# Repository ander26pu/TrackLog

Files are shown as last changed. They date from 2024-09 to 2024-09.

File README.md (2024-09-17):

# TrackLog
- Placa de pruebas: [LILYGO-T18](https://github.com/LilyGO/LILYGO-T-Energy)
- GPS Neo 8MN
- Pantalla OLED 0.96''
- Acelerómetro y giroscopio BMI160
- RTC DS3231
- Módulo micro SD card

## Pines Utilizados

En esta sección se detallan los pines utilizados en el proyecto para los diferentes periféricos conectados al microcontrolador.

| Componente | Pin de Microcontrolador | Función |
|---|---|---|
| **Pantalla OLED (SSD1306)** | I2C SDA (GPIO 21) | Comunicación I2C (SDA) |
| | I2C SCL (GPIO 22) | Comunicación I2C (SCL) |
| **GPS (UART)** | RX1 (GPIO 19) | Recepción de datos (RX) |
| | TX1 (GPIO 18) | Transmisión de datos (TX) |
| **Tarjeta SD** | CS (GPIO 15) | Chip Select (CS) |
| | MOSI (GPIO 13) | Master Out Slave In (MOSI) |
| | MISO (GPIO 12) | Master In Slave Out (MISO) |
| | SCK (GPIO 14) | Serial Clock (SCK) |
| **Acelerómetro/Giroscopio (BMI160)** | I2C SDA (GPIO 21) | Comunicación I2C (SDA) |
| | I2C SCL (GPIO 22) | Comunicación I2C (SCL) |
| **RTC (DS3231)** | I2C SDA (GPIO 21) | Comunicación I2C (SDA) |
| | I2C SCL (GPIO 22) | Comunicación I2C (SCL) |

### Notas adicionales:

- **I2C:** Varios componentes (OLED, acelerómetro/giroscopio, RTC) comparten el bus I2C. Asegúrate de que cada dispositivo tenga una dirección I2C única.
- **SPI:** La tarjeta SD se comunica a través del bus SPI. El pin CS (Chip Select) se define en el código, y el resto de los pines de SPI son comunes a todos los dispositivos SPI.
- **GPS (UART):** El GPS utiliza UART para la comunicación. En este caso, se ha configurado para utilizar UART1.

## PCB TrackLog Shield

Este proyecto incluye el diseño de un **PCB Shield** que se conecta directamente encima de la placa de pruebas [LILYGO-T18](https://github.com/LilyGO/LILYGO-T-Energy). El Shield está diseñado para expandir las capacidades de la placa base, facilitando la conexión de sensores y otros componentes necesarios para el desarrollo del sistema embebido.

### Características del PCB

- **Compatibilidad**: Diseñado específicamente para la placa [LILYGO-T18](https://github.com/LilyGO/LILYGO-T-Energy).
- **Conexiones adicionales**: El Shield incluye pines accesibles para facilitar la conexión de módulos y sensores adicionales.
- **Tamaño compacto**: Encaja directamente sobre la placa LILYGO-T18 sin necesidad de adaptadores adicionales.
- **Facilidad de ensamblaje**: Diseño optimizado para una rápida producción y ensamblaje.

### Esquema del PCB

A continuación se presenta el esquema del diseño del PCB. Este esquema detalla las conexiones entre la placa LILYGO-T18 y los componentes adicionales del Shield.

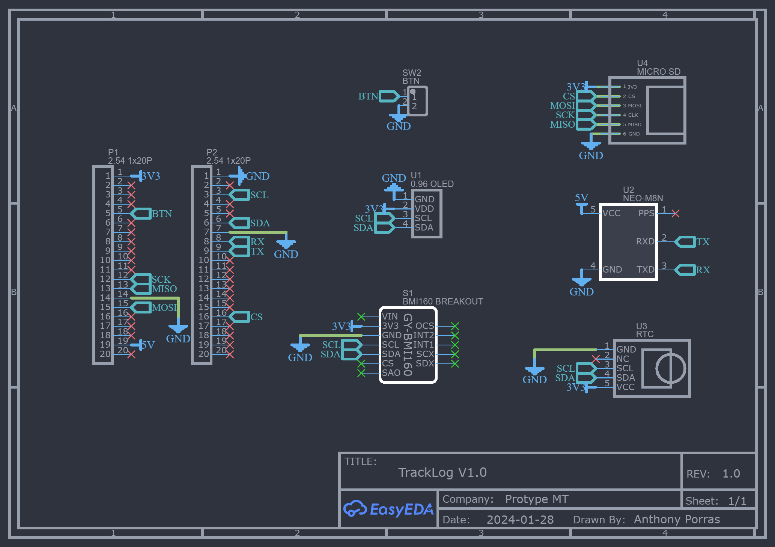
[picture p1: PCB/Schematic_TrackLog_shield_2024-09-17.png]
Esquema del PCB


### Layout del PCB

En el diseño de la PCB se utilizó un ancho de pista de 0.5mm y un espaciado de 0.25mm.

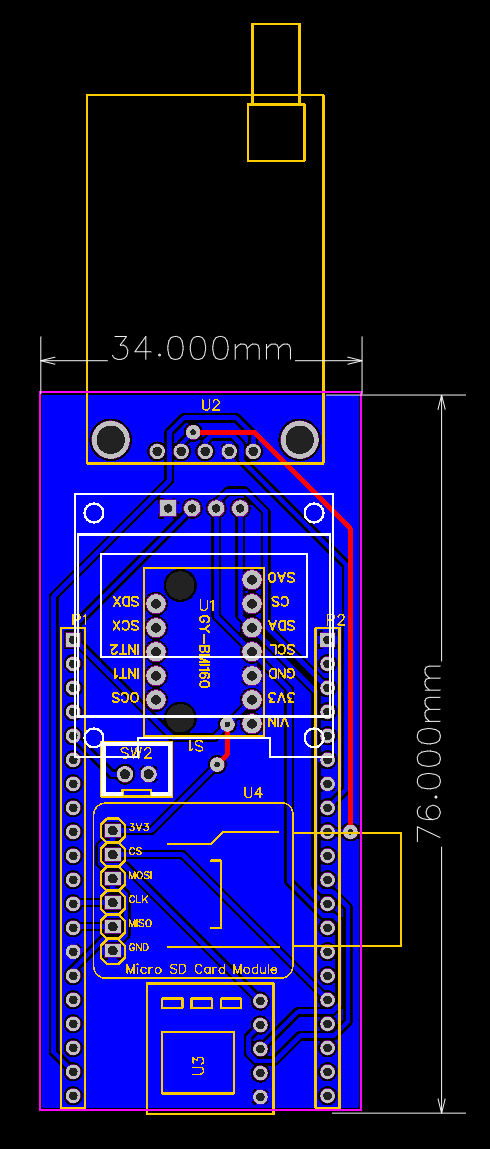
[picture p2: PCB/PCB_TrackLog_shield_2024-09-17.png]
Layout del PCB


### Archivos Gerber y BOM

Puedes descargar los archivos Gerber para la fabricación del Shield desde el siguiente enlace:

- [Archivos Gerber](PCB/Gerber_PCB_TrackLog_shield_2024-09-17.zip)

### Instrucciones de Montaje

1. **Fabricación**: Utiliza los archivos Gerber para fabricar el PCB.
2. **Componentes**: Sigue la lista de materiales para obtener los componentes necesarios.
3. **Soldadura**: Ensambla los componentes siguiendo el esquema proporcionado.
4. **Montaje en LILYGO-T18**: Coloca el Shield directamente encima de la placa LILYGO-T18, alineando los pines correctamente.

### Vista del PCB ensamblado

Aquí puedes ver cómo luce el PCB Shield una vez ensamblado y conectado a la placa LILYGO-T18:

PCB ensamblado

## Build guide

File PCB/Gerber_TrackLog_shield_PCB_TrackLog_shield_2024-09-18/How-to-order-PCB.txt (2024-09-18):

How to Order PCB

Please refer to:
https://docs.easyeda.com/en/PCB/Order-PCB

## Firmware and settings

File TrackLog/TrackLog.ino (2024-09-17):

// Script: TrackLog V1.0
// Description: Guarda datos del gps con las aceleraciones con fecha y hora en una micro sd, mostrando el estado en una pantalla OLED
// Autor: @ander26pu
// Fecha: 2024-09-16
// Board: LILYGO-T18
// Description: Guarda datos del GPS con las aceleraciones con fecha y hora en una micro SD, mostrando el estado en una pantalla OLED

// Board: LILYGO-T18

#include <Wire.h>
#include <Adafruit_GFX.h>
#include <Adafruit_SSD1306.h>
#include <TinyGPSPlus.h>
#include <HardwareSerial.h>
#include <SPI.h>  // Biblioteca para comunicación SPI
#include <SD.h>   // Biblioteca para manejar la tarjeta SD
#include <DFRobot_BMI160.h>
#include "RTClib.h"

#define I2C_SDA 21
#define I2C_SCL 22

#define SCREEN_WIDTH 128 // Ancho de la pantalla OLED
#define SCREEN_HEIGHT 64 // Alto de la pantalla OLED

// Definir el pin de reinicio, si no se usa, define como -1
#define OLED_RESET    -1

#define HSPI_MISO   12
#define HSPI_MOSI   13
#define HSPI_SCK    14
#define SD_CS_PIN   15  // Cambia este pin según tu diseño

File myFile;

// Inicializar la pantalla con la dirección I2C predeterminada 0x3C
Adafruit_SSD1306 display(SCREEN_WIDTH, SCREEN_HEIGHT, &Wire, OLED_RESET);

// Inicializar la comunicación serial para el GPS
HardwareSerial serialGPS(1); // Usamos UART1 (GPIO 19 y 18 para RX/TX)
TinyGPSPlus gps;             // Instancia del objeto TinyGPSPlus

RTC_DS3231 rtc;

DFRobot_BMI160 bmi160;

const int8_t i2c_addr = 0x69;

void setup() {
  Serial.begin(115200);
  delay(100);
  
  Wire.begin(I2C_SDA, I2C_SCL);
  
  iniciarRTC();
  iniciarBMI160();
  iniciarSD();
  iniciarPantallaOLED();
  iniciarGPS();
}

void loop() {
  leerGPS();
  mostrarDatosEnPantalla();
  guardarDatosSD();
  delay(1000);  // Retardo para que no saturemos la pantalla y la SD
}

// Función para inicializar el RTC
void iniciarRTC() {
  if (!rtc.begin()) {
    Serial.println("No se pudo encontrar el RTC DS3231");
    while (1);
  }
}

// Función para inicializar el sensor BMI160
void iniciarBMI160() {
  if (bmi160.softReset() != BMI160_OK) {
    Serial.println("Error en el reinicio del BMI160");
    while (1);
  }
  
  if (bmi160.I2cInit(i2c_addr) != BMI160_OK) {
    Serial.println("Error en la inicialización del BMI160");
    while (1);
  }
}

// Función para inicializar la tarjeta SD
void iniciarSD() {
  SPI.begin(HSPI_SCK, HSPI_MISO, HSPI_MOSI, SD_CS_PIN);
  
  if (!SD.begin(SD_CS_PIN)) {
    Serial.println("Fallo en la inicialización de la tarjeta SD.");
    while (1);
  } else {
    Serial.println("Tarjeta SD detectada y lista.");
  }
}

// Función para inicializar la pantalla OLED
void iniciarPantallaOLED() {
  if (!display.begin(SSD1306_SWITCHCAPVCC, 0x3C)) {
    Serial.println(F("Fallo al inicializar la pantalla OLED"));
    for (;;);
  }
  display.clearDisplay();
  display.setTextSize(1);
  display.setTextColor(WHITE);
  display.setCursor(0, 10);
  display.println(F("Esperando GPS..."));
  display.display();
}

// Función para inicializar el GPS
void iniciarGPS() {
  serialGPS.begin(9600, SERIAL_8N1, 19, 18);  // Inicializamos el GPS en UART1
}

// Función para leer datos del GPS
void leerGPS() {
  while (serialGPS.available() > 0) {
    gps.encode(serialGPS.read());
  }
}

// Función para mostrar los datos en la pantalla OLED
void mostrarDatosEnPantalla() {
  display.clearDisplay();
  display.setCursor(0, 0);

  if (gps.location.isValid()) {
    display.println(F("GPS Datos:"));
    display.print(F("Lat: "));
    display.println(gps.location.lat(), 6);
    display.print(F("Lon: "));
    display.println(gps.location.lng(), 6);
    display.print(F("Vel: "));
    display.print(gps.speed.kmph());
    display.println(F(" km/h"));
    display.print(F("Sats: "));
    display.println(gps.satellites.value());
    display.display();
  } else {
    display.println(F("Esperando señal GPS..."));
    display.display();
  }
}

// Función para obtener y guardar los datos en la tarjeta SD
void guardarDatosSD() {
  if (gps.location.isValid()) {
    int16_t accelGyro[6] = {0};
    int rslt = bmi160.getAccelGyroData(accelGyro);

    if (rslt == 0) {
      // Abrimos el archivo en modo append, lo que agrega datos sin sobrescribir
      myFile = SD.open("/data.txt", FILE_APPEND);

      if (myFile) {
        // Verificar si el archivo ya tiene contenido
        if (myFile.size() > 0) {
          // Si ya hay contenido, agregar un salto de línea antes de escribir nuevos datos
          myFile.println();
        }

        // Obtener la hora actual del RTC
        DateTime now = rtc.now();
        
        // Escribir fecha y hora
        myFile.print(now.year(), DEC);
        myFile.print('/');
        myFile.print(now.month(), DEC);
        myFile.print('/');
        myFile.print(now.day(), DEC);
        myFile.print(" ");
        myFile.print(now.hour(), DEC);
        myFile.print(':');
        myFile.print(now.minute(), DEC);
        myFile.print(':');
        myFile.print(now.second(), DEC);
        
        // Escribir datos del GPS
        myFile.print("\tLat: ");
        myFile.print(gps.location.lat(), 6);
        myFile.print("\tLon: ");
        myFile.print(gps.location.lng(), 6);
        myFile.print("\tVel: ");
        myFile.print(gps.speed.kmph());
        myFile.print(" km/h");
        
        // Escribir datos del acelerómetro
        for (int i = 3; i < 6; i++) {
          myFile.print("\tAccel: ");
          myFile.print(accelGyro[i] / 16384.0);
        }
        
        myFile.println();  // Agregamos un salto de línea al final de los datos
        
        myFile.close();  // Cerrar el archivo para guardar los cambios
        Serial.println("Datos guardados correctamente.");
      } else {
        Serial.println("Error al abrir data.txt");
      }
    } else {
      Serial.println("Error al leer los datos del acelerómetro");
    }
  }
}

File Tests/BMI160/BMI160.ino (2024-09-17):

// Script: Test - BMI160 sensor
// Description: Basic demo for accelerometer readings from BMI160
// Autor: @ander26pu
// Fecha: 2024-09-16
// Board: LILYGO-T18
#include <Wire.h>
#include <DFRobot_BMI160.h>

DFRobot_BMI160 bmi160;

// Pines I2C para el ESP32 (ajusta si es necesario)
#define SDA_PIN 21
#define SCL_PIN 22

const int8_t i2c_addr = 0x69;

void setup() {
  // Inicializa la comunicación serie
  Serial.begin(115200);
  delay(100);

  // Configura los pines I2C
  Wire.begin(SDA_PIN, SCL_PIN);
  
  // Reinicia el sensor
  if (bmi160.softReset() != BMI160_OK) {
    Serial.println("Error en el reinicio del BMI160");
    while(1);
  }
  
  // Inicializa el BMI160 en la dirección I2C especificada
  if (bmi160.I2cInit(i2c_addr) != BMI160_OK) {
    Serial.println("Error en la inicialización del BMI160");
    while(1);
  }
}

void loop() {
  int i = 0;
  int rslt;
  int16_t accelGyro[6] = {0}; 
  
  // Obtén los datos de acelerómetro y giroscopio
  rslt = bmi160.getAccelGyroData(accelGyro);
  if(rslt == 0) {
    for(i = 0; i < 6; i++) {
      if (i < 3) {
        // Los primeros tres son datos del giroscopio
        Serial.print("Gyro: ");
        Serial.print(accelGyro[i] * 3.14 / 180.0); // Convertir a radianes
        Serial.print("\t");
      } else {
        // Los últimos tres son datos del acelerómetro
        Serial.print("Accel: ");
        Serial.print(accelGyro[i] / 16384.0); // Escala del acelerómetro
        Serial.print("\t");
      }
    }
    Serial.println();
  } else {
    Serial.println("Error en la lectura de datos");
  }
  delay(100);
}

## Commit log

2024-09-17 Se corrigió que no se sobrescriba la data, con FILE_APPEND
    [TrackLog.ino]
2024-09-17 Se agregagó la sección de pines utilizados
2024-09-17 Se agregaron imágenes del esquemático y del diseño de la PCB
2024-09-17 Se agregó la sección de PCB Shield
2024-09-17 Se agregaron los archivos gerber
2024-09-17 Se colocó el enlace del archivo gerber
2024-09-18 Archivos Gerber corregidos
    [Drill_NPTH_Through.DRL, Drill_PTH_Through.DRL, Drill_PTH_Through_Via.DRL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]
2024-09-18 Archivos gcode para la fabircación en cnc
